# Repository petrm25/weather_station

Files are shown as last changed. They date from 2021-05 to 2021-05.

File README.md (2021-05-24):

# weather_station
## Description
Source files for a weather station project. Measuring temperature, humidity, pressure, wind direction and speed, rainfall, UV index as well as soil moisture and temperature at 3 depths.
## Folders
### PCBs
Gerber, drill as well as bom files are located in PCBs folder. 
### Source codes
In this folder you can find source codes for both used microntrollers.
### 3D models
Contains all created holders for sensors, battery, etc. File format is .STL and .STEP.
## List of sensors used in this project
* Anemometer, wind vane and rain gauge from WH1080
* BME280
* VEML6075
* 3x Capacitive soil moisture sensor v2.0
* 3x DS18B20 waterproof
## License
``weather_station`` is released under the MIT License.

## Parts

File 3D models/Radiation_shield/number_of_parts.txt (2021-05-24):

Number of parts to be printed on a 3D printer and then assembled

1x Holder
1x Cross
1x Top plate
1x Top plate bme280 holder
1x Top cover plate UV sensor
1x Bottom cover plate
2x Bottom plate
6x Middle plate

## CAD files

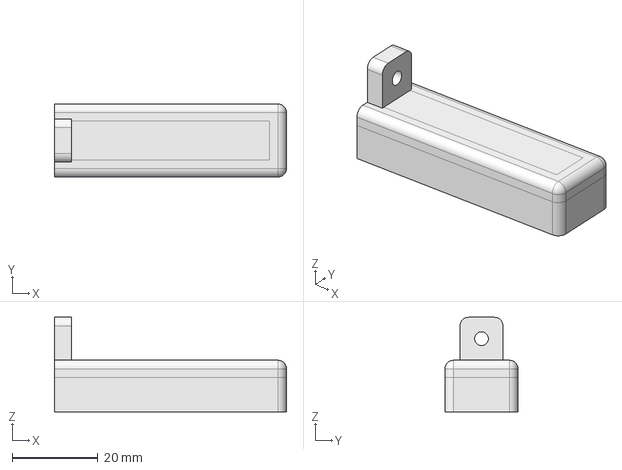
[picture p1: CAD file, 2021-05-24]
3D models/Battery_holder/Battery_holder_bottom.step
54.0 x 17.0 x 22.0 mm

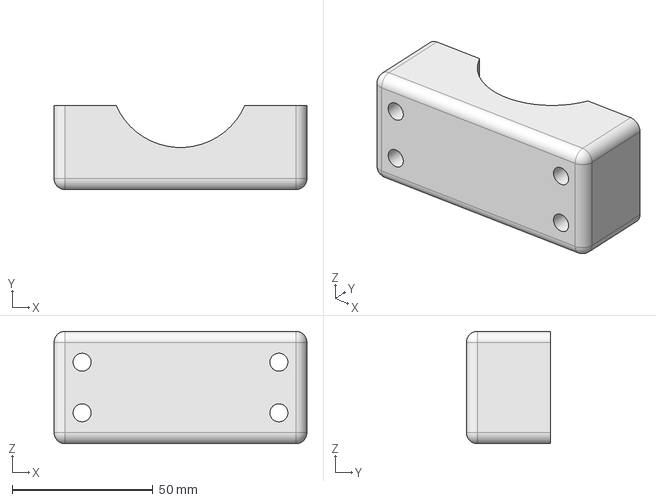
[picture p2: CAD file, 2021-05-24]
3D models/Case/case_clamp.step
90.0 x 30.0 x 40.0 mm

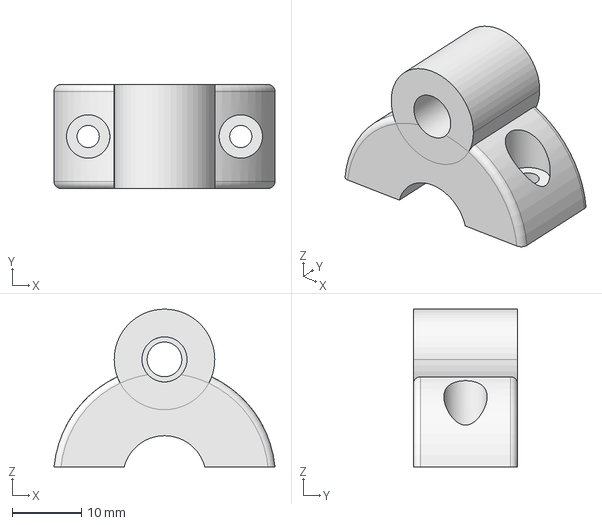
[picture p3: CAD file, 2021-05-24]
3D models/DS18B20_holder/ds18b20_holder.step
31.9 x 15.0 x 22.7 mm

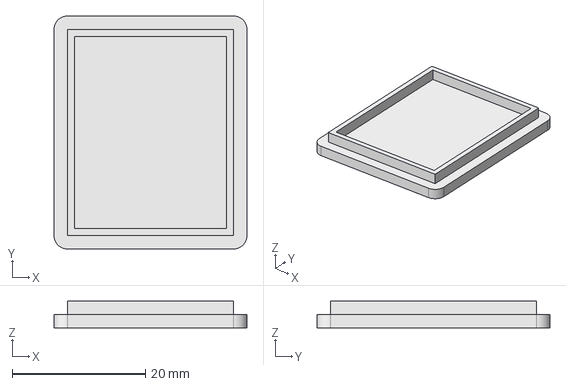
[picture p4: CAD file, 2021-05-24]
3D models/Protective_case/top_cover.step
29.0 x 35.0 x 4.00 mm

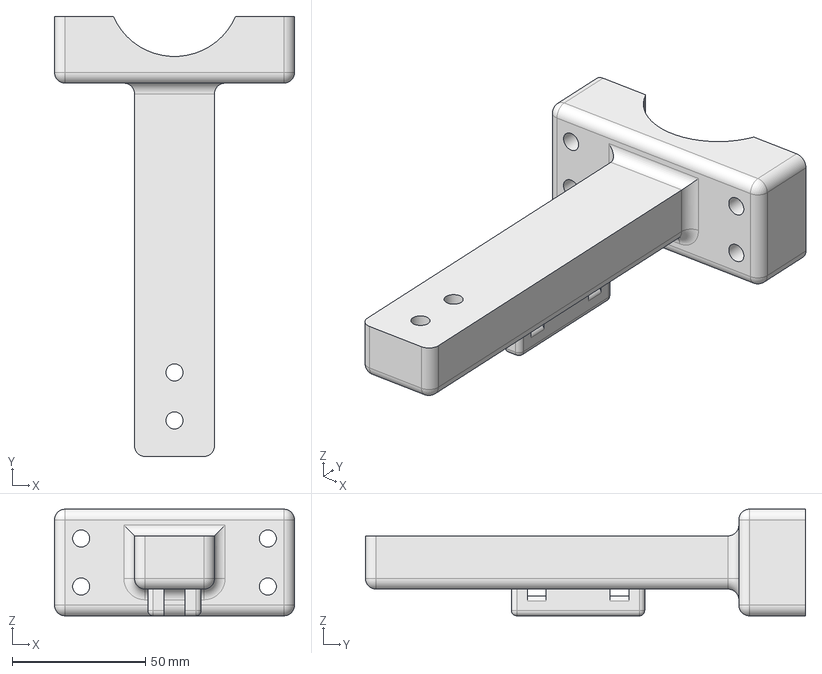
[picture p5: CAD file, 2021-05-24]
3D models/Radiation_shield/STEP/Holder.step
90.0 x 165.0 x 40.0 mm

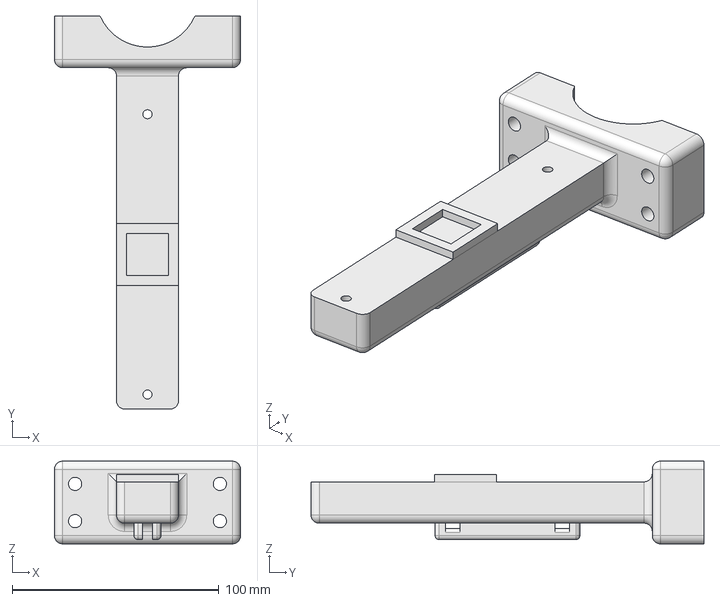
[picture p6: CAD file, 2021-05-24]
3D models/Rain_gauge_holder/Rain_gauge_holder.step
90.0 x 190.0 x 40.0 mm

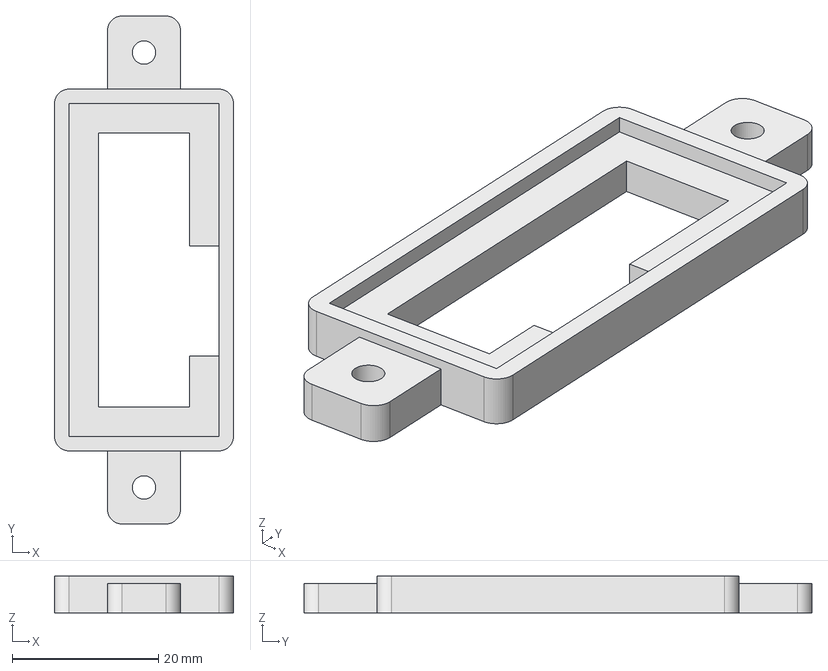
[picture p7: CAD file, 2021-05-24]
3D models/Solar_charger_holder/solar_charger_holder.step
24.5 x 69.5 x 5.00 mm

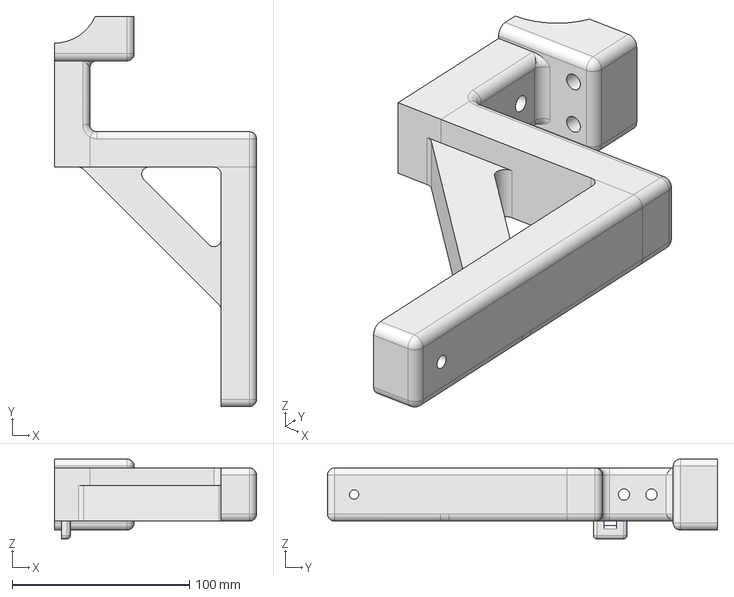
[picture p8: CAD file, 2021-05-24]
3D models/Solar_panel_holder/Solar_panel_holder_right.step
114.0 x 220.0 x 45.0 mm

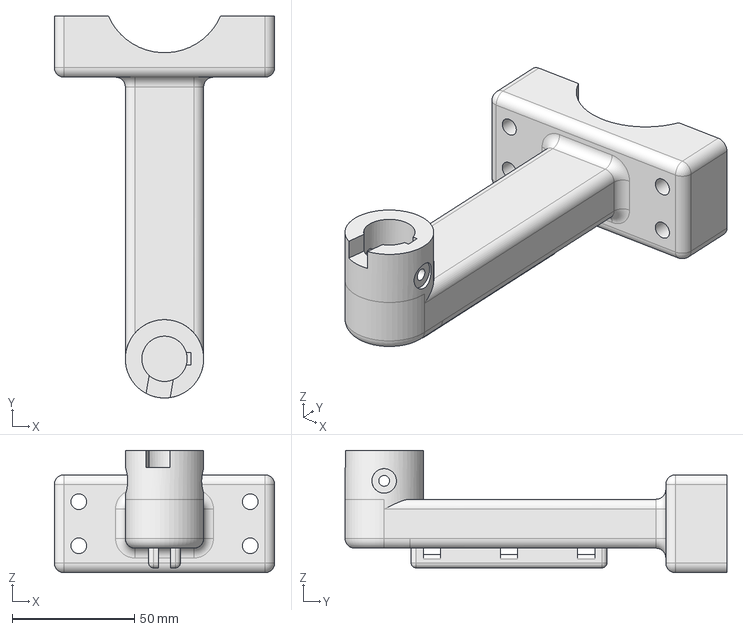
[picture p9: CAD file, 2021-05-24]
3D models/Wind_gauge_holder/Wind_gauge_holder.step
90.0 x 156.0 x 50.0 mm

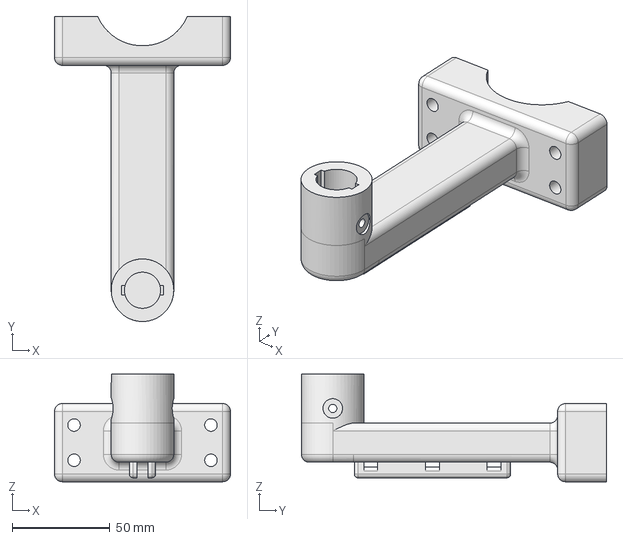
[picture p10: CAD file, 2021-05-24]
3D models/Wind_wane_holder/wind_wane_holder.step
90.0 x 156.0 x 55.0 mm

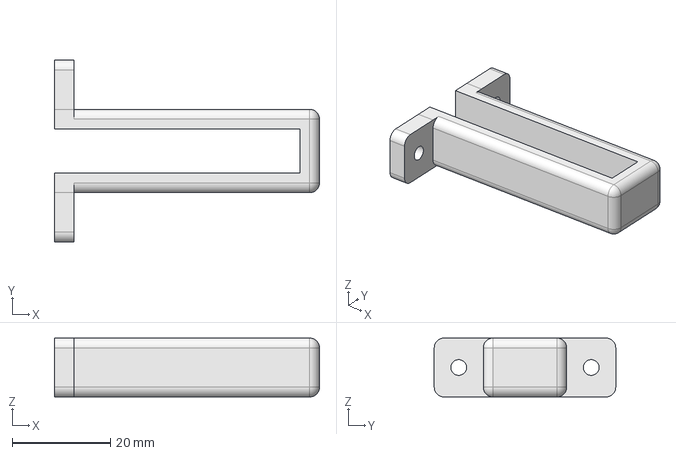
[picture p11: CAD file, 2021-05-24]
3D models/Battery_holder/Battery_holder_top.step
54.0 x 37.0 x 12.0 mm

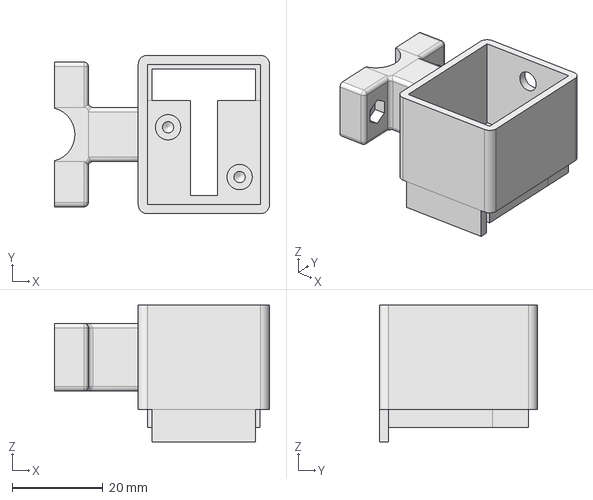
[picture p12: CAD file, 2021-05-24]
3D models/Protective_case/middle.step
47.5 x 35.0 x 30.2 mm

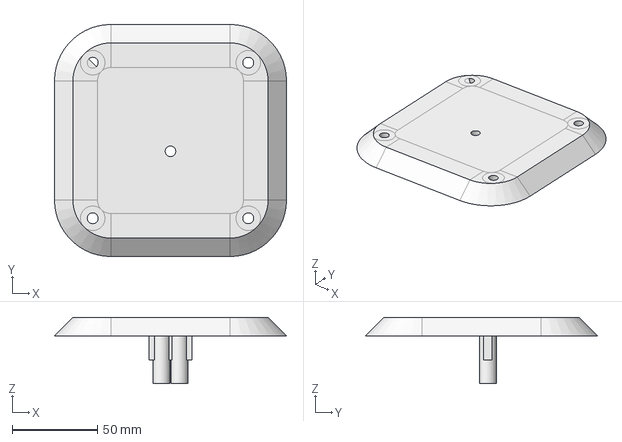
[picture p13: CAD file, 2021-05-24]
3D models/Radiation_shield/STEP/Top_plate_bme280_holder.step
136.0 x 136.0 x 38.7 mm

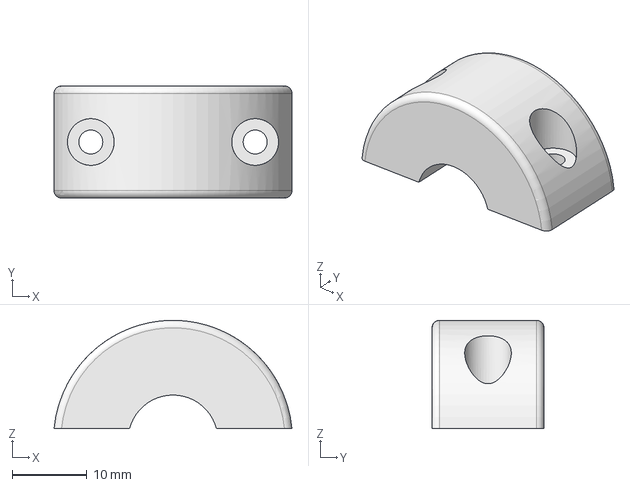
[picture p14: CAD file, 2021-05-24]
3D models/Protective_case/clamp.step
31.9 x 15.0 x 14.5 mm

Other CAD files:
3D models/Solar_panel_holder/Solar_panel_holder_left.step
3D models/Radiation_shield/STEP/Top_plate.step
3D models/Protective_case/bottom.step
3D models/Radiation_shield/STEP/Middle_plate.step
3D models/Battery_holder/Battery_holder_bottom.stl
3D models/Battery_holder/Battery_holder_top.stl
3D models/Case/case_clamp.stl
3D models/DS18B20_holder/ds18b20_holder.stl
3D models/Protective_case/bottom.stl
3D models/Protective_case/clamp.stl
3D models/Protective_case/middle.stl
3D models/Protective_case/top_cover.stl
3D models/Radiation_shield/STEP/Bottom_cover_plate.step
3D models/Radiation_shield/STEP/Bottom_plate.step
3D models/Radiation_shield/STEP/Cross.step
3D models/Radiation_shield/STEP/Top_cover_plate_UV_sensor.step
3D models/Radiation_shield/STL/Bottom_cover_plate.stl
3D models/Radiation_shield/STL/Bottom_plate.stl
3D models/Radiation_shield/STL/Cross.stl
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

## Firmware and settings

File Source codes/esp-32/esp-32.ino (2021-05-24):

#include "driver/rtc_io.h"

#include <WiFi.h>
#include <WiFiClient.h>
#include <WebServer.h>
#include <Wire.h>
#include <Adafruit_Sensor.h>
#include <Adafruit_BME280.h>
#include <SPIFFS.h>
#include <SoftwareSerial.h>
#include <OneWire.h>
#include <DallasTemperature.h>
#include <rom/rtc.h>
#include "Adafruit_VEML6075.h"
#include "ThingSpeak.h"

#define BUTTON_PIN_BITMASK 0x8000

#define toSecondFactor 1000
hw_timer_t *timer = NULL;

#define TIMEOUT 5000

#define ENABLE 12
#define SDA 23
#define SCL 22
#define ONE_WIRE_BUS 16
#define windDir 34
#define GAL 32
#define GAU 33
#define GBL 25
#define GBU 26
#define RCLK 27
#define CCLR 13
#define CLK_INH 18
#define CNTR 35
#define SH_LD 2
#define CLK 4
#define BAT_V 36

#define BME280_SENSOR_ADDRESS (0x76)
Adafruit_BME280 bme;

Adafruit_VEML6075 uv = Adafruit_VEML6075();


OneWire oneWire(ONE_WIRE_BUS);

DallasTemperature sensors(&oneWire);
uint8_t sensor1[8] = {0x28, 0xDC, 0xA2, 0x63, 0x2D, 0x19, 0x01, 0x8B};
uint8_t sensor2[8] = {0x28, 0x31, 0x58, 0x56, 0x2D, 0x19, 0x01, 0x3A};
uint8_t sensor3[8] = {0x28, 0xA5, 0xB2, 0x65, 0x2D, 0x19, 0x01, 0xF0};

SoftwareSerial softSerial(21, 19);

WiFiClient client;
WebServer server(80);

const char *badRequest = "<!DOCTYPE html><html lang='cs-cz'><head><meta http-equiv='refresh' content='3; url=http://192.168.4.1/settings' /><link rel='stylesheet' href='bootstrap.min.css'><meta name='viewport' content='width=device-width, initial-scale=1, shrink-to-fit=no'><title>Meteostanice</title></head><body><div class='container'><p><div class='row'><div class='col-sm-12'><h1>Meteostanice</h1><h3>Nevyplnili jste prislusna pole</h3><h6>Budete presmerovani</h6></div></div></p></div></body></html>";
const char *successfulRequest = "<!DOCTYPE html><html lang='cs-cz'><head><meta http-equiv=\'content-type\' content=\'text/html\' ; charset=\'utf-8\'><link rel='stylesheet' href='bootstrap.min.css'><meta name='viewport' content='width=device-width, initial-scale=1, shrink-to-fit=no'><title>Meteostanice</title></head><body><div class='container'><p><div class='row'><div class='col-sm-12'><h1>Meteostanice</h1><h3>Ulozeni uspesne</h3></div></div></p></div></body></html>";

//Default SSID and password to start AP
const char *ssid = "IoT system";
const char *password = "IoTsystem32";

bool bmeInitialized = false;
bool uvInitialized = false;

//Variables to store all data
float temp1;
float temp2;
float temp3;
float temperature;
float humidity;
double pressure;
float windSpd;
float rainAmmount;
float angle = 0;
String dir;
float moisture1;
float moisture2;
float moisture3;
float batteryVoltage;
float uvIndex;

bool configSaved = false;

//Variable which is set in ISR to true if reset button is pressed during the on time
volatile bool eraseConf = false;

volatile uint32_t count = 0;

//Set default mode of operation to 2, 1 means periodical wakeup to send data, 2 continuous mode
uint8_t mode = 2;
//If mode is set to 1,
uint8_t sendMode;
//Arrays to store credentials for HTTP Basic auth
char www_username[40];
char www_password[40];
//Arrays to store credentials to connect to WiFi or create AP
char ssid_in[40];
char password_in[40];
//Varible to store time to sleep in minutes
uint8_t sleepTime;
//Varibles to store Thingspeak channel IDs and API keys
unsigned long channelId1;
unsigned long channelId2;
char APIkey[20];
char APIkey2[20];
//Array to store URL or IP address of custom server to send data
char url_ip[50];
//Arrays to store depth of sensors to be shown on web page
char depth_Temperature_1[40] = "0";
char depth_Temperature_2[40] = "0";
char depth_Temperature_3[40] = "0";
char depth_Moisture_1[40] = "0";
char depth_Moisture_2[40] = "0";
char depth_Moisture_3[40] = "0";

void IRAM_ATTR timerISR()
{
  count++;
}

void IRAM_ATTR eraseConfISR()
{
  eraseConf = true;
}

void setup()
{
  pinMode(15, INPUT_PULLUP);
  attachInterrupt(digitalPinToInterrupt(15), eraseConfISR, FALLING);
  // initialize serial port
  while (!Serial)
  {
  }
  getResetReason(rtc_get_reset_reason(0));
  esp_sleep_wakeup_cause_t wakeup_reason;

  wakeup_reason = esp_sleep_get_wakeup_cause();

  if (!SPIFFS.begin(true))
  {
    return;
  }

  switch (wakeup_reason)
  {
    case ESP_SLEEP_WAKEUP_EXT0:
      break;
    case ESP_SLEEP_WAKEUP_EXT1:
      eraseConfig();
      esp_restart();
      break;
    case ESP_SLEEP_WAKEUP_TIMER:
      break;
    case ESP_SLEEP_WAKEUP_TOUCHPAD:
      break;
    case ESP_SLEEP_WAKEUP_ULP:
      break;
    default:
      {
        break;
      }
  }

  if (SPIFFS.exists("/mode.txt"))
  {
    configSaved = true;
    loadConfig();
  }

  if (mode == 2)
  {
    timer = timerBegin(0, 80, true);       
    timerAttachInterrupt(timer, &timerISR, true);
    timerAlarmWrite(timer, 1000, true);
    timerAlarmEnable(timer);
    createAP();
    prepareForRead();
  }
}

void loop()
{
  if (eraseConf)
  {
    eraseConfig();
    esp_restart();
  }

  if (mode == 1)
  {

    prepareForRead();
    delay(3000); //Wait a while to stabilize value returned by moisture sensors
    getAllData();
    sendData();
    if (eraseConf)
    {
      eraseConfig();
      esp_restart();
    }
    esp_sleep_enable_ext1_wakeup(BUTTON_PIN_BITMASK, ESP_EXT1_WAKEUP_ALL_LOW);
    rtc_gpio_pullup_en(GPIO_NUM_15);
    rtc_gpio_pulldown_dis(GPIO_NUM_15);
    rtc_gpio_hold_en(GPIO_NUM_15);
    esp_sleep_enable_timer_wakeup(sleepTime * 60 * 1e6 - (millis() * 1000));
    esp_deep_sleep_start();
  }
  else
  {
    server.handleClient();
  }
}

void resetCounter()
{
  pinMode(CCLR, OUTPUT);
  digitalWrite(CCLR, LOW);
  delayMicroseconds(10);
  digitalWrite(CCLR, HIGH);
}

void createAP()
{
  WiFi.mode(WIFI_AP_STA);

  if (configSaved)
  {
    WiFi.softAP(ssid_in, password_in, 13, false, 4);
  }
  else
  {
    WiFi.softAP(ssid, password, 13, false, 4);
  }

  server.on("/", handleIndex);
  server.on("/settings", handleSettings);
  server.on("/json", handleJson);
  server.on("/getXML", sendXMLData);
  server.on("/getXMLWifi", sendXMLWifi);
  server.on("/uloz", saveConfig);
  server.on("/javascript.js", handleJavascript);
  server.on("/pure-min.css", handleCss);
  server.begin();
}

void sendData()
{
  uint16_t i = 0;
  char floatArray[20];
  snprintf(floatArray, sizeof floatArray, "%.2f", temperature);
  temperature = (float)atof(floatArray);
  snprintf(floatArray, sizeof floatArray, "%.2f", humidity);
  humidity = (float)atof(floatArray);
  snprintf(floatArray, sizeof floatArray, "%.2lf", pressure);
  pressure = atof(floatArray);
  snprintf(floatArray, sizeof floatArray, "%.2f", windSpd);
  windSpd = (float)atof(floatArray);
  snprintf(floatArray, sizeof floatArray, "%.2f", angle);
  angle = (float)atof(floatArray);
  snprintf(floatArray, sizeof floatArray, "%.2f", rainAmmount);
  rainAmmount = (float)atof(floatArray);
  snprintf(floatArray, sizeof floatArray, "%.2f", uvIndex);
  uvIndex = (float)atof(floatArray);

  snprintf(floatArray, sizeof floatArray, "%.2f", temp1);
  temp1 = (float)atof(floatArray);
  snprintf(floatArray, sizeof floatArray, "%.2f", temp2);
  temp2 = (float)atof(floatArray);
  snprintf(floatArray, sizeof floatArray, "%.2f", temp3);
  temp3 = (float)atof(floatArray);
  snprintf(floatArray, sizeof floatArray, "%.2f", moisture1);
  moisture1 = (float)atof(floatArray);
  snprintf(floatArray, sizeof floatArray, "%.2f", moisture2);
  moisture2 = (float)atof(floatArray);
  snprintf(floatArray, sizeof floatArray, "%.2f", moisture3);
  moisture3 = (float)atof(floatArray);
  snprintf(floatArray, sizeof floatArray, "%.2f", batteryVoltage);
  batteryVoltage = (float)atof(floatArray);

  WiFi.mode(WIFI_STA);
  WiFi.begin(ssid_in, password_in);

  while ((WiFi.status() != WL_CONNECTED) && (i < 20000))
  {
    delay(1);
    i++;
  }

  if (WiFi.status() == WL_CONNECTED)
  {
    if (sendMode == 1)
    {
      ThingSpeak.begin(client);
      ThingSpeak.setField(1, temperature);
      ThingSpeak.setField(2, humidity);
      ThingSpeak.setField(3, (float)pressure);
      ThingSpeak.setField(4, windSpd);
      ThingSpeak.setField(5, angle);
      ThingSpeak.setField(6, rainAmmount);
      ThingSpeak.setField(7, uvIndex);
      int x = ThingSpeak.writeFields(channelId1, APIkey);

      ThingSpeak.setField(1, temp1);
      ThingSpeak.setField(2, temp2);
      ThingSpeak.setField(3, temp3);
      ThingSpeak.setField(4, moisture1);
      ThingSpeak.setField(5, moisture2);
      ThingSpeak.setField(6, moisture3);
      ThingSpeak.setField(7, batteryVoltage);

      x = ThingSpeak.writeFields(channelId2, APIkey2);
    }
    else
    {
      String message;
      message = "teplota=";
      message += String(temperature, 1);
      message += "&vlhkost=";
      message += String(humidity, 1);
      message += "&tlak=";
      message += String(pressure, 1);
      message += "&rychlost_vetru=";
      message += String(windSpd, 1);
      message += "&smer_vetru=";
      message += String(angle, 1);

      message += "&srazky=";
      message += String(rainAmmount, 2);
      message += "&uvindex=";
      message += String(uvIndex, 1);
      message += "&teplota_pudy_";
      message += String(depth_Temperature_1);
      message += "cm=";
      message += String(temp1, 1);
      message += "&teplota_pudy_";
      message += String(depth_Temperature_2);
      message += "cm=";
      message += String(temp2, 1);
      message += "&teplota_pudy_";
      message += String(depth_Temperature_3);
      message += "cm=";
      message += String(temp3, 1);

      message += "&vlhkost_pudy_";
      message += String(depth_Moisture_1);
      message += "cm=";
      message += String(moisture1, 1);
      message += "&vlhkost_pudy_";
      message += String(depth_Moisture_2);
      message += "cm=";
      message += String(moisture2, 1);
      message += "&vlhkost_pudy_";
      message += String(depth_Moisture_3);
      message += "cm=";
      message += String(moisture3, 1);
      message += "&napeti_baterie=";
      message += String(batteryVoltage, 2);

      if (client.connect(url_ip, 80))
      {
        client.print("POST /update HTTP/1.1\n");
        client.print("Connection: close\n");
        client.print("Content-Type: application/x-www-form-urlencoded\n");
        client.print("Content-Length: ");
        client.print(message.length());
        client.print("\n\n");
        client.print(message);

        String answer = getResponse();
      }
      else
      {
        //Error connecting to server
      }
    }
  }
  else
  {
    //Error connecting to WiFi
  }
}

String getResponse()
{
  String response;
  long startTime = millis();

  delay(200);
  while (client.available() < 1 && ((millis() - startTime) < TIMEOUT))
  {
    delay(5);
  }

  if (client.available() > 0)
  {
    char symbol;
    do
    {
      symbol = client.read();
      response += symbol;
    } while (client.available() > 0);
  }
  client.stop();

  return response;
}

void handleIndex()
{
  File htmlFile = SPIFFS.open("/index.html", "r");
  server.streamFile(htmlFile, "text/html");
  htmlFile.close();
}

void handleJavascript()
{
  File javascriptFile = SPIFFS.open("/javascript.js", "r");
  server.streamFile(javascriptFile, "text/javascript");
  javascriptFile.close();
}

void handleCss()
{
  File cssFile = SPIFFS.open("/pure-min.css", "r");
  server.streamFile(cssFile, "text/css");
  cssFile.close();
}

void handleSettings()
{
  const char *www_username_default = "admin";
  const char *www_password_default = "esp32";
  if (!configSaved)
  {
    if (!server.authenticate(www_username_default, www_password_default))
    {
      return server.requestAuthentication();
    }
    File settings = SPIFFS.open("/settings.html", "r");
    server.streamFile(settings, "text/html");
    settings.close();
  }
  else
  {
    if (!server.authenticate(www_username, www_password))
    {
      return server.requestAuthentication();
    }
    File settings = SPIFFS.open("/settings.html", "r");
    server.streamFile(settings, "text/html");
    settings.close();
  }
}

void handleJson()
{
  getAllData();
  char jsonBuffer[500];
  char floatArray[10];
  snprintf(floatArray, sizeof floatArray, "%.2f", temperature);
  strcpy(jsonBuffer, "{\"teplota:\" ");
  strcat(jsonBuffer, floatArray);

  snprintf(floatArray, sizeof floatArray, "%.2f", humidity);
  strcat(jsonBuffer, ", \"vlhkost:\" ");
  strcat(jsonBuffer, floatArray);

  snprintf(floatArray, sizeof floatArray, "%.2f", pressure);
  strcat(jsonBuffer, ", \"tlak:\" ");
  strcat(jsonBuffer, floatArray);

  snprintf(floatArray, sizeof floatArray, "%.2f", windSpd);
  strcat(jsonBuffer, ", \"rychlost vetru:\" ");
  strcat(jsonBuffer, floatArray);

  snprintf(floatArray, sizeof floatArray, "%.2f", angle);
  strcat(jsonBuffer, ", \"smer vetru:\" ");
  strcat(jsonBuffer, floatArray);

  snprintf(floatArray, sizeof floatArray, "%.2f", rainAmmount);
  strcat(jsonBuffer, ", \"mnozstvi srazek:\" ");
  strcat(jsonBuffer, floatArray);

  snprintf(floatArray, sizeof floatArray, "%.1f", uvIndex);
  strcat(jsonBuffer, ", \"uv index:\" ");
  strcat(jsonBuffer, floatArray);

  snprintf(floatArray, sizeof floatArray, "%.2f", temp1);
  strcat(jsonBuffer, ", \"teplota pudy ");
  strcat(jsonBuffer, depth_Temperature_1);
  strcat(jsonBuffer, " cm:\" ");
  strcat(jsonBuffer, floatArray);

  snprintf(floatArray, sizeof floatArray, "%.2f", temp2);
  strcat(jsonBuffer, ", \"teplota pudy ");
  strcat(jsonBuffer, depth_Temperature_2);
  strcat(jsonBuffer, " cm:\" ");
  strcat(jsonBuffer, floatArray);

  snprintf(floatArray, sizeof floatArray, "%.2f", temp3);
  strcat(jsonBuffer, ", \"teplota pudy ");
  strcat(jsonBuffer, depth_Temperature_3);
  strcat(jsonBuffer, " cm:\" ");
  strcat(jsonBuffer, floatArray);

  snprintf(floatArray, sizeof floatArray, "%.2f", moisture1);
  strcat(jsonBuffer, ", \"vlhkost pudy ");
  strcat(jsonBuffer, depth_Moisture_1);
  strcat(jsonBuffer, " cm:\" ");
  strcat(jsonBuffer, floatArray);

  snprintf(floatArray, sizeof floatArray, "%.2f", moisture2);
  strcat(jsonBuffer, ", \"vlhkost pudy ");
  strcat(jsonBuffer, depth_Moisture_2);
  strcat(jsonBuffer, " cm:\" ");
  strcat(jsonBuffer, floatArray);

  snprintf(floatArray, sizeof floatArray, "%.2f", moisture3);
  strcat(jsonBuffer, ", \"vlhkost pudy ");
  strcat(jsonBuffer, depth_Moisture_3);
  strcat(jsonBuffer, " cm:\" ");
  strcat(jsonBuffer, floatArray);

  snprintf(floatArray, sizeof floatArray, "%.2f", batteryVoltage);
  strcat(jsonBuffer, ", \"napeti baterie:\" ");
  strcat(jsonBuffer, floatArray);
  strcat(jsonBuffer, "}");
  server.send(200, "application/json; charset=utf-8", jsonBuffer);
}

void sendXMLData()
{
  getAllData();
  char xmlBuffer[800];
  char floatArray[10];

  strcpy(xmlBuffer, "<?xml version = \"1.0\" ?><inputs>");

  snprintf(floatArray, sizeof floatArray, "%.2f", temperature);
  strcat(xmlBuffer, "<reading>");
  strcat(xmlBuffer, floatArray);
  strcat(xmlBuffer, "</reading>\n");
  snprintf(floatArray, sizeof floatArray, "%.2f", humidity);
  strcat(xmlBuffer, "<reading>");
  strcat(xmlBuffer, floatArray);
  strcat(xmlBuffer, "</reading>\n");
  snprintf(floatArray, sizeof floatArray, "%.2f", pressure);
  strcat(xmlBuffer, "<reading>");
  strcat(xmlBuffer, floatArray);
  strcat(xmlBuffer, "</reading>\n");

  snprintf(floatArray, sizeof floatArray, "%.2f", windSpd);
  strcat(xmlBuffer, "<reading>");
  strcat(xmlBuffer, floatArray);
  strcat(xmlBuffer, "</reading>\n");

  strcat(xmlBuffer, "<reading>");
  strcat(xmlBuffer, dir.c_str());
  strcat(xmlBuffer, "</reading>\n");
  snprintf(floatArray, sizeof floatArray, "%.2f", rainAmmount);
  strcat(xmlBuffer, "<reading>");
  strcat(xmlBuffer, floatArray);
  strcat(xmlBuffer, "</reading>\n");

  snprintf(floatArray, sizeof floatArray, "%.2f", uvIndex);
  strcat(xmlBuffer, "<reading>");
  strcat(xmlBuffer, floatArray);
  strcat(xmlBuffer, "</reading>\n");

  snprintf(floatArray, sizeof floatArray, "%.2f", temp1);
  strcat(xmlBuffer, "<reading>");
  strcat(xmlBuffer, floatArray);
  strcat(xmlBuffer, "</reading>\n");
  snprintf(floatArray, sizeof floatArray, "%.2f", temp2);
  strcat(xmlBuffer, "<reading>");
  strcat(xmlBuffer, floatArray);
  strcat(xmlBuffer, "</reading>\n");
  snprintf(floatArray, sizeof floatArray, "%.2f", temp3);
  strcat(xmlBuffer, "<reading>");
  strcat(xmlBuffer, floatArray);
  strcat(xmlBuffer, "</reading>\n");
  snprintf(floatArray, sizeof floatArray, "%.2f", moisture1);
  strcat(xmlBuffer, "<reading>");
  strcat(xmlBuffer, floatArray);
  strcat(xmlBuffer, "</reading>\n");
  snprintf(floatArray, sizeof floatArray, "%.2f", moisture2);
  strcat(xmlBuffer, "<reading>");
  strcat(xmlBuffer, floatArray);
  strcat(xmlBuffer, "</reading>\n");
  snprintf(floatArray, sizeof floatArray, "%.2f", moisture3);
  strcat(xmlBuffer, "<reading>");
  strcat(xmlBuffer, floatArray);
  strcat(xmlBuffer, "</reading>\n");

  snprintf(floatArray, sizeof floatArray, "%.2f", batteryVoltage);
  strcat(xmlBuffer, "<reading>");
  strcat(xmlBuffer, floatArray);
  strcat(xmlBuffer, "</reading>\n");

  strcat(xmlBuffer, "<placeholder>");
  strcat(xmlBuffer, depth_Temperature_1);
  strcat(xmlBuffer, "</placeholder>\n");
  strcat(xmlBuffer, "<placeholder>");
  strcat(xmlBuffer, depth_Temperature_2);
  strcat(xmlBuffer, "</placeholder>\n");
  strcat(xmlBuffer, "<placeholder>");
  strcat(xmlBuffer, depth_Temperature_3);
  strcat(xmlBuffer, "</placeholder>\n");
  strcat(xmlBuffer, "<placeholder>");
  strcat(xmlBuffer, depth_Moisture_1);
  strcat(xmlBuffer, "</placeholder>\n");
  strcat(xmlBuffer, "<placeholder>");
  strcat(xmlBuffer, depth_Moisture_2);
  strcat(xmlBuffer, "</placeholder>\n");
  strcat(xmlBuffer, "<placeholder>");
  strcat(xmlBuffer, depth_Moisture_3);
  strcat(xmlBuffer, "</placeholder>\n");

  strcat(xmlBuffer, "</inputs>");
  server.send(200, "text/xml", xmlBuffer);
}

void sendXMLWifi()
{
  char charBuffer[800] = "\0";
  char xmlBuffer[850];
  char RSSIbuffer[10];

  int n = WiFi.scanComplete();
  if (n == -2)
  {
    WiFi.scanNetworks(true, true);
    strcpy(xmlBuffer, "<?xml version = \"1.0\" ?><inputs>");
    strcat(xmlBuffer, "<reading>");
    strcat(xmlBuffer, "Scanning");
    strcat(xmlBuffer, "</reading>\n");
    strcat(xmlBuffer, "</inputs>");
    server.send(200, "text/xml", xmlBuffer);
  }
  else if (n == -1)
  {
    strcpy(xmlBuffer, "<?xml version = \"1.0\" ?><inputs>");
    strcat(xmlBuffer, "<reading>");
    strcat(xmlBuffer, "Scanning...");
    strcat(xmlBuffer, "</reading>\n");
    strcat(xmlBuffer, "</inputs>");
    server.send(200, "text/xml", xmlBuffer);
  }
  else if (n)
  {
    for (int i = 0; i < n; i++)
    {
      if (WiFi.SSID(i) == "")
      {
        strcat(charBuffer, "*HIDDEN_SSID*");
      }
      else
      {
        strcat(charBuffer, WiFi.SSID(i).c_str());
      }
      strcat(charBuffer, "  Sila signalu: ");
      itoa(WiFi.RSSI(i), RSSIbuffer, 10);
      strcat(charBuffer, RSSIbuffer);
      if (WiFi.encryptionType(i) == WIFI_AUTH_OPEN)
      {
        strcat(charBuffer, " dBm&lt;br&gt;");
      }
      else
      {
        strcat(charBuffer, " dBm &#x1F512;&lt;br&gt;");
      }
    }
    strcpy(xmlBuffer, "<?xml version = \"1.0\" ?><inputs>");
    strcat(xmlBuffer, "<reading>");
    strcat(xmlBuffer, charBuffer);
    strcat(xmlBuffer, "</reading>\n");
    strcat(xmlBuffer, "</inputs>");
    server.send(200, "text/xml", xmlBuffer);
    WiFi.scanDelete();
    if (WiFi.scanComplete() == -2)
    {
      WiFi.scanNetworks(true, true);
    }
  }
}

void prepareForRead()
{

  pinMode(windDir, INPUT);
  pinMode(ENABLE, OUTPUT);
  digitalWrite(ENABLE, HIGH);
  delay(10);
  softSerial.begin(9600);
  Wire.begin(SDA, SCL);
  delay(10);
  sensors.begin();
  if (!bme.begin(BME280_SENSOR_ADDRESS))
  {
  }
  else
  {
    bme.setSampling(Adafruit_BME280::MODE_FORCED);
    bmeInitialized = true;
  }

  if (!uv.begin())
  {
  }
  else
  {
    uvInitialized = true;
  }

  while (softSerial.available() > 0)
  {
    softSerial.read();
  }

  digitalWrite(GAL, HIGH);
  digitalWrite(GAU, HIGH);
  digitalWrite(GBL, HIGH);
  digitalWrite(GBU, HIGH);
  pinMode(GAL, OUTPUT);
  pinMode(GAU, OUTPUT);
  pinMode(GBL, OUTPUT);
  pinMode(GBU, OUTPUT);

  digitalWrite(GAL, HIGH);
  digitalWrite(GAU, HIGH);
  digitalWrite(GBL, HIGH);
  digitalWrite(GBU, HIGH);

  pinMode(RCLK, OUTPUT);
  digitalWrite(RCLK, LOW);
  digitalWrite(CCLR, HIGH);
  pinMode(CCLR, OUTPUT);
  digitalWrite(CCLR, HIGH);

  pinMode(CLK, OUTPUT);
  pinMode(CLK_INH, OUTPUT);
  digitalWrite(CLK_INH, LOW);
  digitalWrite(SH_LD, HIGH);
  pinMode(SH_LD, OUTPUT);
  digitalWrite(SH_LD, HIGH);
  pinMode(CNTR, INPUT);
}

void getAllData()
{
  sensors.requestTemperatures();
  sensors.requestTemperatures();
  temp1 = getTemperature(sensor1);
  temp2 = getTemperature(sensor2);
  temp3 = getTemperature(sensor3);
  getAtmosphericData();
  getWindDirection();

  if (uvInitialized)
  {
    uvIndex = uv.readUVI();
  }
  else
  {
    uvIndex = 9999.99;
  }

  getWindSpd_Rain();
  batteryVoltage = getBatteryVoltage();

  moisture1 = getSoilMoisture(1);
  moisture2 = getSoilMoisture(2);
  moisture3 = getSoilMoisture(3);
}

void getAtmosphericData()
{
  if (bmeInitialized)
  {
    bme.takeForcedMeasurement();
    temperature = bme.readTemperature();
    humidity = bme.readHumidity();
    pressure = (bme.readPressure() / 100.0F);
  }
  else
  {
    temperature = 9999.99;
    humidity = 9999.99;
    pressure = 9999.99;
  }
}
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

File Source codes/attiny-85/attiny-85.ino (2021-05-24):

const int Rx = 3;
const int Tx = 4;
const byte Ad_in = 1;
#include <SoftwareSerial.h>
SoftwareSerial softSerial(Rx, Tx);

byte r = 0;
char incoming;
char receivedData[8];

char start_symbol = '#';
int address_in;
char start_symbol_in;

char upperByte = 0;
char lowerByte = 0;

int intArray[6];
int n = 6;
char address = 3;
bool received = false;

void setup() {
  softSerial.begin(9600);
  pinMode(Ad_in, INPUT);
  delay(10);
}

void loop() {
  if (softSerial.available() > 0) {
    delay(7);

    while (softSerial.available() > 0) {

      incoming = softSerial.read();
      receivedData[r] = incoming;
      r++;
      received = true;
    }
    r = 0;
  }
  if (received == true) {
    received = false;
    start_symbol_in = receivedData[0];
    address_in = receivedData[1];

    if (start_symbol_in == '#') {
      if (address_in == 3) {
        for (int i = 0; i < 6; i++) {
          intArray[i] = analogRead(Ad_in);
          delay(2);
        }
        sort(intArray, n);
        int value = round(Find_median(intArray, n));
        lowerByte = value & 0xFF;
        upperByte = value >> 8;
        softSerial.print(start_symbol);
        softSerial.print(address);
        softSerial.print(upperByte);
        softSerial.print(lowerByte);
      }
    }
  }
}

void swap(int *p, int *q) {
  int t;
  t = *p;
  *p = *q;
  *q = t;
}

void sort(int pole[], int n) {
  int i, j, temp;
  for (i = 0; i < n - 1; i++) {
    for (j = 0; j < n - i - 1; j++) {
      if (pole[j] > pole[j + 1])
        swap(&pole[j], &pole[j + 1]);
    }
  }
}

float Find_median(int pole[] , int n)
{
  float median = 0;
  if (n % 2 == 0)
    median = (pole[(n - 1) / 2] + pole[n / 2]) / 2.0;
  else
    median = pole[n / 2];
  return median;
}
